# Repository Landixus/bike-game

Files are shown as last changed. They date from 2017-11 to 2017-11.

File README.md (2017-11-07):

# Arduino Bike Game
[Watch the video demo here](https://youtu.be/r04d039daLk)

My 2015 [High School](http://www.scienceandmathacademy.com/) Capstone Project with mentorship from Christopher Rogers.
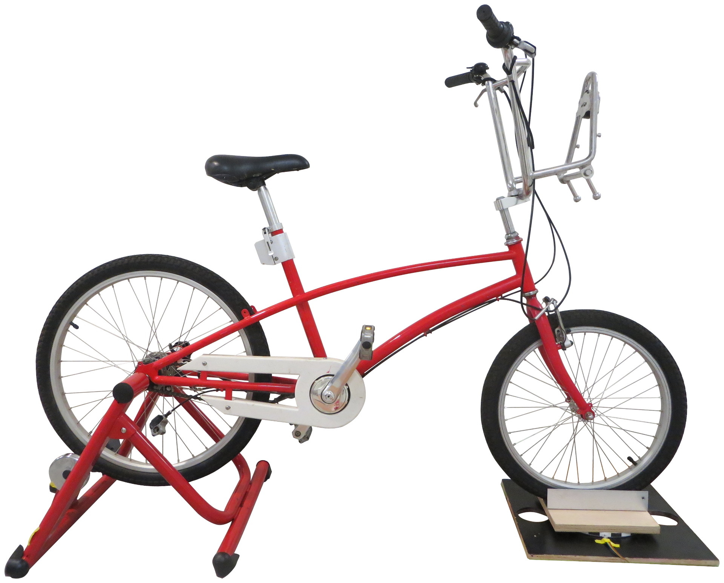
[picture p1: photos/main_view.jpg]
main view
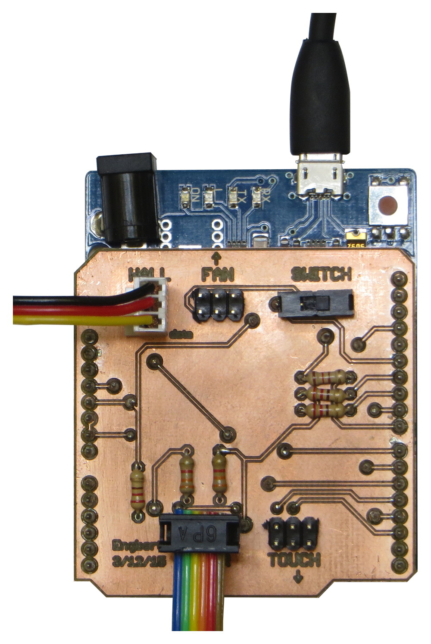
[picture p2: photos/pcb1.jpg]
  

### PURPOSE:
To enable a stationary bike to control computer games so that a biker can race in a game while exercising.

### HOW IT WORKS:
The Arduino Leonardo is plugged into a computer where it emulates a keyboard and constantly measures the bike's speed (RPM) and checks that state of the steering.  In the game, the vehicle’s speed and steering are varied by rapidly modulating the arrow key presses sent to the computer by the Leonardo.
For example: if the bike is above the goal RPM (defined as a constant in the code) then it will effectively press the up arrow continously; and at 50% of the goal speed the up arrow will be pressed 50% of the time on average by the Leonardo.

### RESULTS:
* The system is able to control any racing computer game that can be controlled by arrow keys.
* The faster the biker pedals, the faster the race car will go.
* The sharper the biker turns, the sharper the rac car will turn.
* Read the [project poster](https://github.com/danielengbert/bike-game/blob/master/project_poster.pdf) and watch the [video demo](https://youtu.be/r04d039daLk).

### REQUIREMENTS:
* Arduino Leonardo
* custom printed circuit board (see EAGLE CAD files in the PCB folder)
  * and a few resistors and cables
* hall effect sensor
* neodymium magnet
* 1 IR emmiter and 2 IR receivers (serve as a photointerrupter for the steering)
* lazy susan (for the bike's front tire)
* bike and stationary bike stand

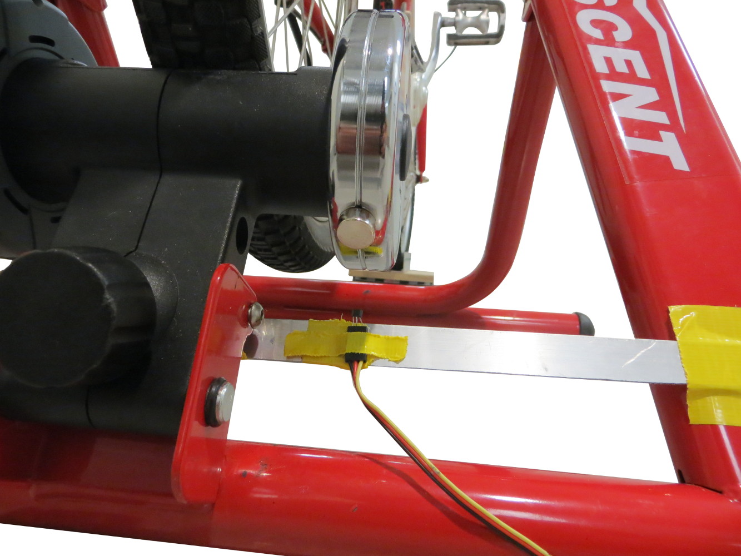
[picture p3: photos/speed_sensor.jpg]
speed sensor
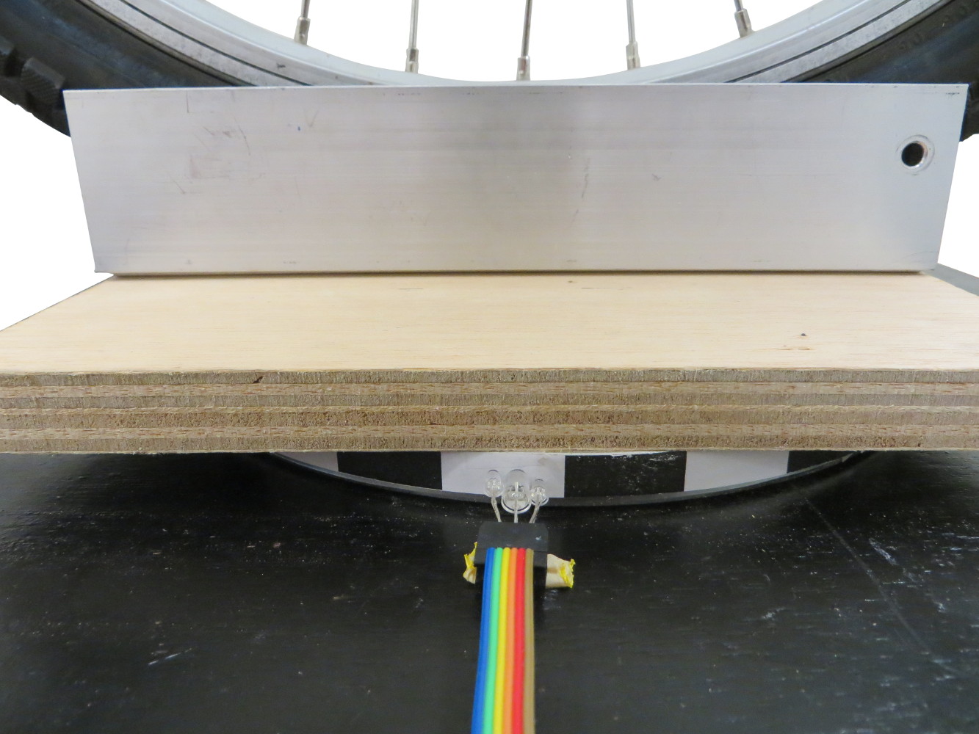
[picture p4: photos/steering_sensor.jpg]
steering sensor
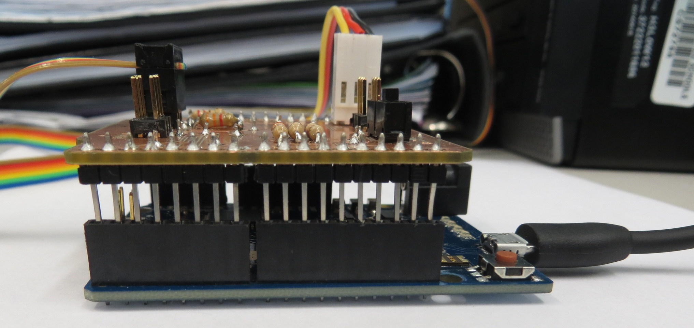
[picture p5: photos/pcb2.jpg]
   

### NOTE:
The next phase of this project would be to add capacitive touch sensor to the bike's handlebar for more game control (like activating turbo) and also to add a fan that blows air on the biker at a strength relative to their bike speed.  Preliminary development of this portion of the project was started and built into the PCB.

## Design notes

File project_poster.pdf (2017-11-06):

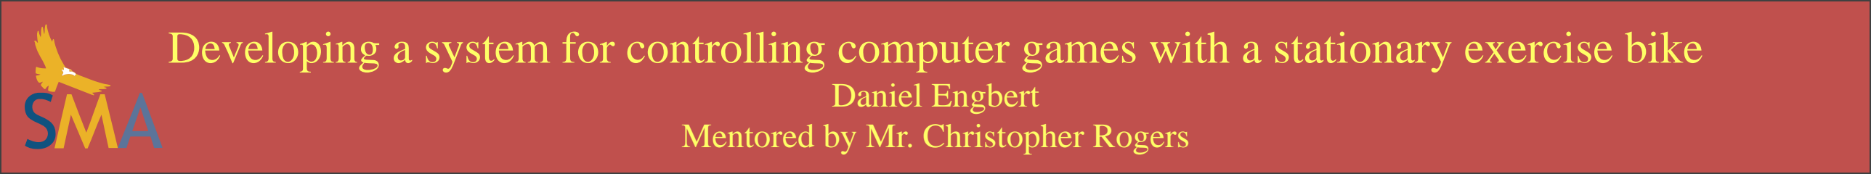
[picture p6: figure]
Daniel Engbert Mentored by Mr. Christopher Rogers

# Developing a system for controlling computer games with a stationary exercise bike

## Introduction

Nearly half the U.S. adult population does not get enough aerobic exercise each week ("Adult Participation," 2013). As a result, many Americans are putting themselves at a greater risk of cardiovascular disease, type 2 diabetes, and even some cancers (“Physical Activity and Health,” 2011).
The idea of exercise is often unappealing to people, and they instead opt for sedentary activities such as video games. This project aimed to combine exercise and video games to create an exciting environment where one can receive the benefits of cardio exercise while playing a computer game. The project focused on creating a system where any computer racing game could be controlled by exercising on a stationary bike.

## Methods and Materials

## Conclusions

## Methods and Materials (cont.)

In order to verify the consistency and accuracy of the system, the calculated rpm values were compared to the actual rpm (as determined by observing the Hall effect sensor with an oscilloscope) for two trials. The distributions of calculated rpm values for the trials are shown in Graph 1 and 2. The low and high rpm trial had standard deviations of 0.593 and 3.16 respectively. The steering was tested for 1000 turn iterations and no issues were present; the program consistently kept track of the position of the front tire.
The variable speed fan was never fully implemented. The Leonardo and Uno were able to successfully communicate the desired fan speed, but the Uno was unable to correctly set the fan speed all of the time. The issues stemmed from the fan failing to consistently receive the IR signal from the Uno.

Centers For Disease Control and Prevention. (2011). Physical activity and health. Retrieved from http://www.cdc.gov/physicalactivity/everyone/health/ Centers For Disease Control and prevention. (2013). Adult participation in aerobic and muscle-strengthening physical activities — United States, 2011. Retrieved from http://www.cdc.gov/mmwr/preview/mmwrhtml/mm6217a2.htm

## References

An Arduino

® Leonardo microcontroller connected to the sensors through a custom PCB and sent keyboard commands to the computer through a USB cable (Figure 2). A computer racing game was then controlled by the keyboard commands sent from the Leonardo. In the computer game, the vehicle’s speed and steering were varied by rapidly modulating the arrow key presses sent to the computer. An Arduino

® Uno was also utilized to receive commands from the Leonardo and to send IR commands to a remote controlled variable speed fan; setting its power level relative to that of the cyclist’s speed.

A bicycle was mounted on a resistance trainer for stationary use (see Figure 1). A magnet was placed on the trainer’s fly wheel so that it would be rotated by the back tire when the user pedaled. A Hall effect sensor was then attached beneath the wheel to allow the cyclist’s speed to be calculated (Figure 3). A bracket was constructed and affixed to a Lazy Susan for the bike’s front tire to rest in. An IR LED and two phototransistors were pointed at a black and white grid bordering the Lazy Susan (Figure 4) allowing the direction and magnitude of the bike’s steering to be measured.

## Results (cont.)

The goal to create a system allowing computer racing games to be controlled by a stationary bike was accomplished. The project’s speed and steering input methods were determined to be sufficient for modulated control of game-play.
The issues with the variable speed fan could be overcome if a sensor was added for the Uno to check the fan’s current speed level. This would enable the Uno to identify when the fan failed to receive a signal, and then resend it as needed.
The project could be further expanded by incorporating a mobile app. The app could allow the user to alter the settings based on the specific computer game, adjust the exercise intensity, and provide feedback on the user’s biking speed. Additionally, a multiplayer setup with two or more bikes could be constructed.

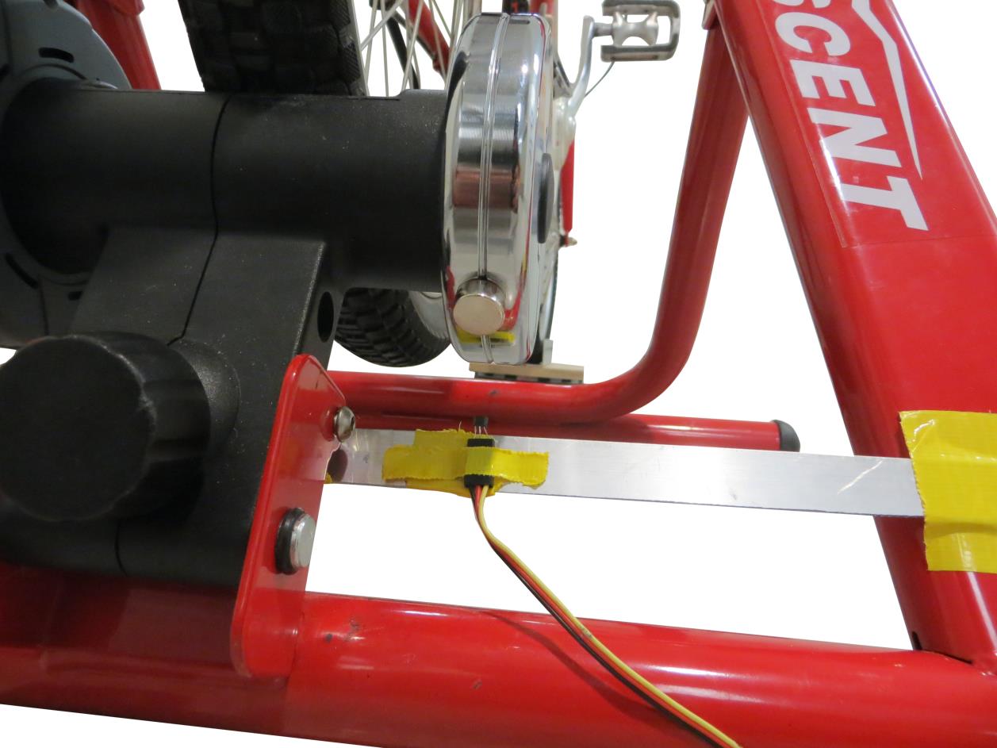
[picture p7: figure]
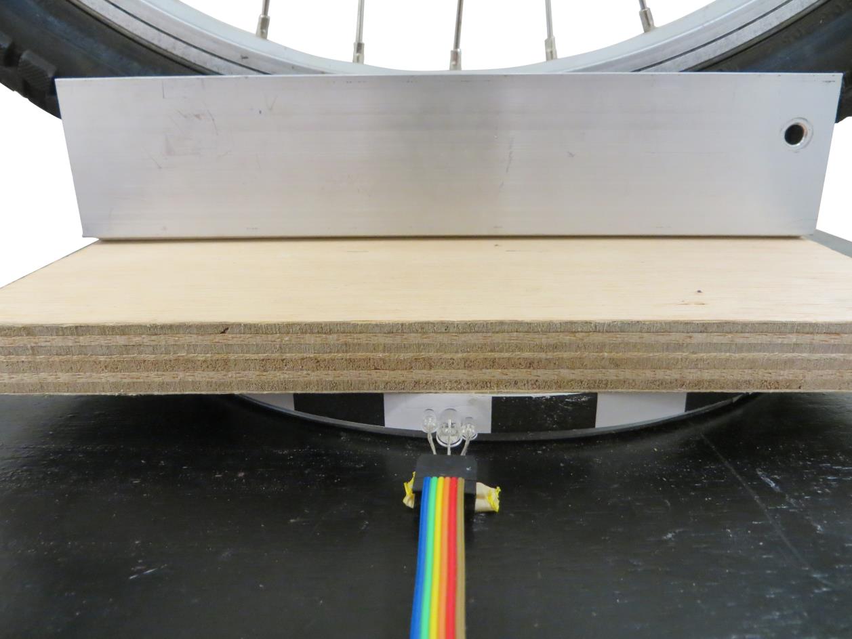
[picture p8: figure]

Figure 3: The Hall effect sensor mounted beneath the fly wheel of the bike stand. A magnet attached to the wheel was detected | Figure 4: The bike’s front tire resting in the Lazy Susan. An IR LED was mounted between two phototransistors pointed at the
by the sensor after each rotation, allowing the user’s speed to be calculated. | black and white grid for measuring the direction and magnitude of the user’s steering.

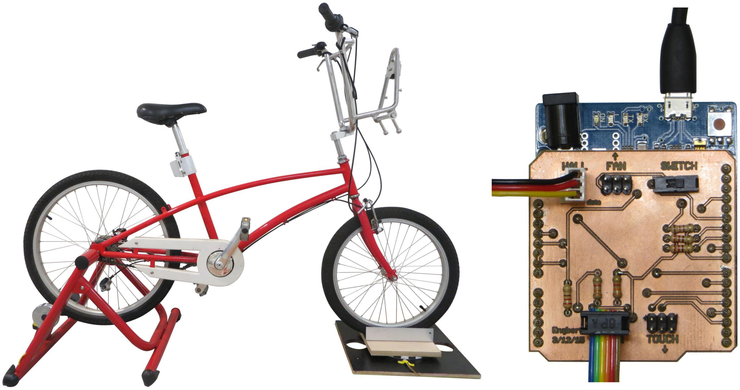
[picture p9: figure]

Figure 1: A bike with its rear wheel mounted on the resistance trainer and the front tire resting in the bracket on the Lazy Susan.

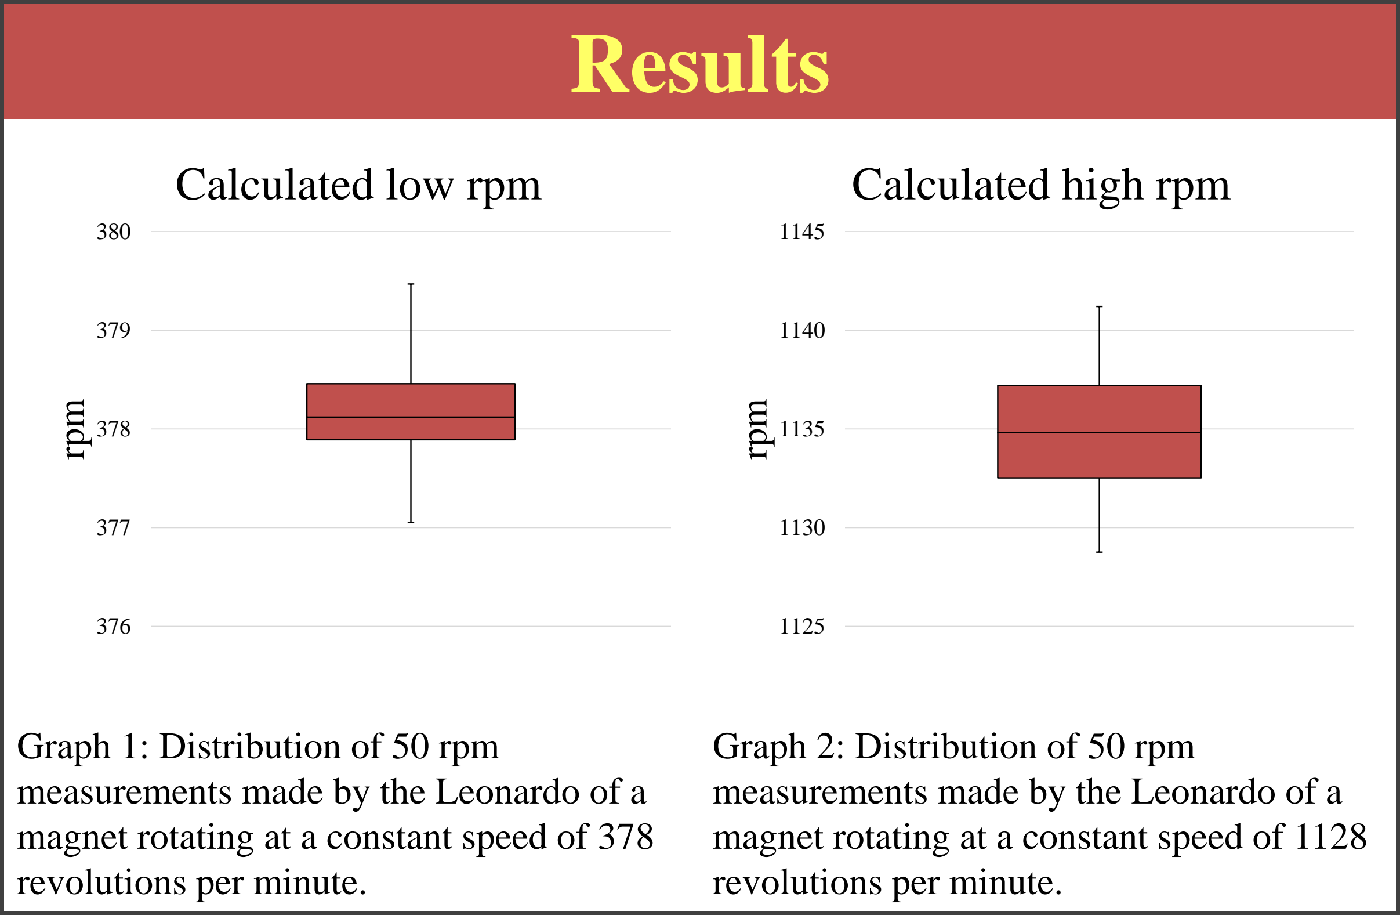
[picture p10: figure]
Results; rpm; Calculated low rpm; Calculated high rpm

Graph 1: Distribution of 50 rpm | Graph 2: Distribution of 50 rpm
measurements made by the Leonardo of a magnet rotating at a constant speed of 378 revolutions per minute. | measurements made by the Leonardo of a magnet rotating at a constant speed of 1128 revolutions per minute.

Figure 2: The custom PCB
plugged into the Arduino®
Leonardo with the connected Hall effect and steering
sensors.

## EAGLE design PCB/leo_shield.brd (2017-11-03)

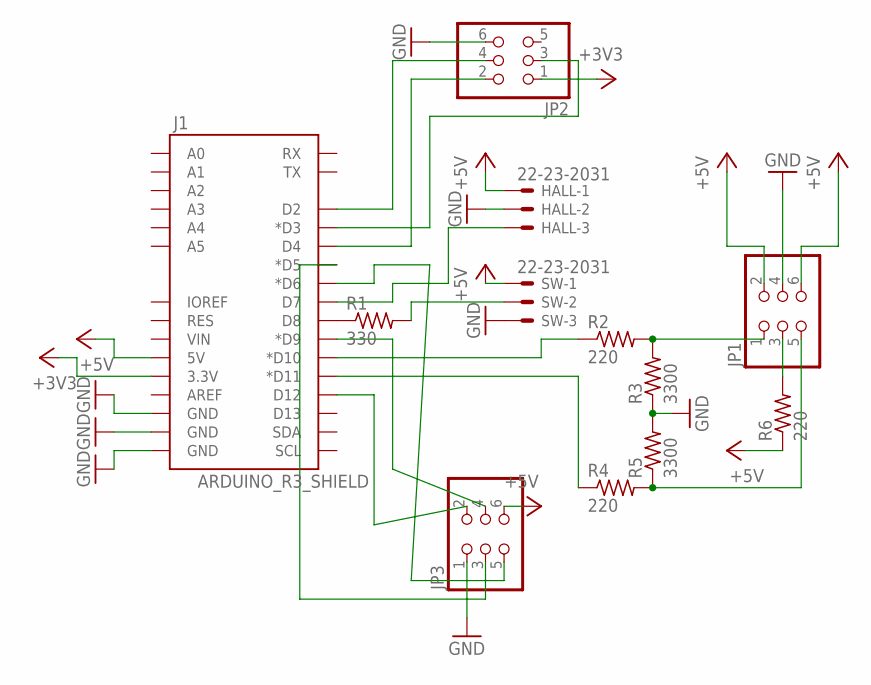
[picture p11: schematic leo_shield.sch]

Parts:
HALL: 22-23-2031
J1: ARDUINO_R3_SHIELD; UNO_R3_SHIELD
JP1, JP2, JP3: PINHD-2X3; 2X03
R1: 330; 0204/7
R2, R4, R6: 220; 0204/7
R3, R5: 3300; 0204/7
SW: 22-23-2031

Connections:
+3V3: J1.3.3V, JP2.1
+5V: HALL.1, J1.5V, JP1.2, JP1.6, JP3.6, R6.1, SW.1
GND: HALL.2, J1.GND@0 (GND), J1.GND@1 (GND), J1.GND@2 (GND), JP1.4, JP2.6, JP3.1, R3.1, R5.2, SW.3
IR: JP1.1, R2.2, R3.2
unnamed: J1.D12, JP3.2
unnamed: JP1.3, R6.2
unnamed: R1.2, SW.2
unnamed: J1.D11 (*D11), R4.1
unnamed: J1.D8, R1.1
unnamed: HALL.3, J1.D7
unnamed: JP1.5, R4.2, R5.1
unnamed: J1.D4, JP2.2
unnamed: J1.D2, JP2.4
unnamed: J1.D3 (*D3), JP2.3
unnamed: J1.D10 (*D10), R2.1
unnamed: J1.D9 (*D9), JP3.4
unnamed: J1.D5 (*D5), JP3.3
unnamed: J1.D6 (*D6), JP3.5

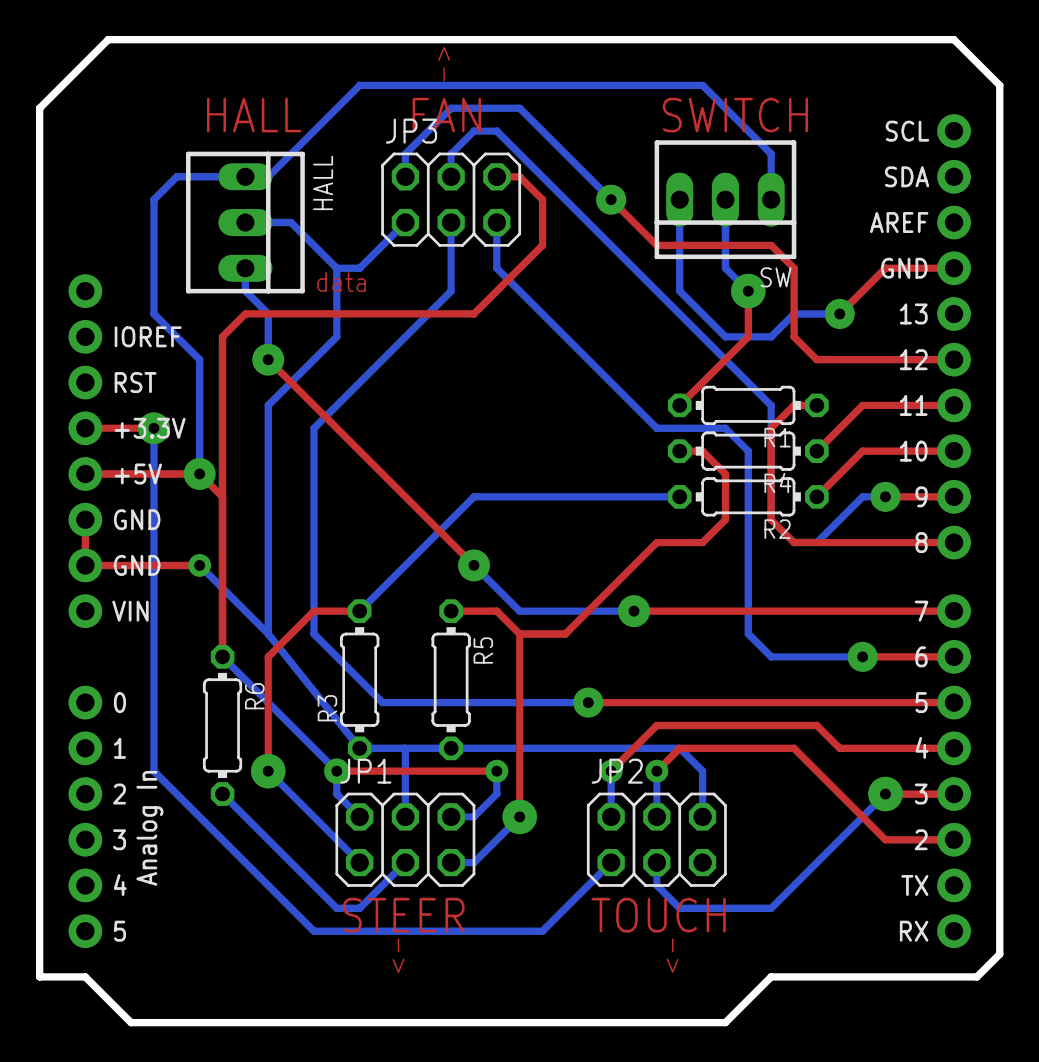
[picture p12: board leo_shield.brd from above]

Board: 2 copper layers, 53.3 x 54.6 mm, 12 parts (0 on the bottom side), 18 nets.

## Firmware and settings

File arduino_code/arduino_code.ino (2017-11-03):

#include "mpr121.h"
#include <Wire.h>
//RPM VARIABLES:
volatile int count = 0; //variable declerations
volatile long cTime = 0; //volatile lets the variable be accessed in all functions
volatile long lastTime = 0;
volatile long period;
volatile double rpm = 0;
//SPEED VARIABLES:
const int goal = 2000;
const int interval = 100;
int speedTime = 0;
double speedStart = 0;
double speedStop; //rename speedspeedStop or speedStop
//STEERING VARIABLES:
double turnStart = 0;
double turnStop;
double factor;
int oldright=0;
int right;
int oldleft=0;
int left;
int same; //value of the last color that both detected
double total = 0;
//TOUCHPAD Variables:
int irqpin = 4;  // Digital 2
boolean touchStates[12]; //array of 12 booleans- keeps track of the previous touch states
boolean state=true;

int sumRPM=0;
int numTurns=0;


//:::SETUP:::
void setup(){
  Serial.begin(9600); //allows the serial monitor to display outputs
  Keyboard.begin();
  Wire.begin();
  attachInterrupt(4, rotationCounter, RISING); //rotationCounter function runs when LEONARDO board pin7 (the interrupt pin 4)
                                               //rises (goes from a low to high)
  pinMode(irqpin, INPUT);
  digitalWrite(irqpin, HIGH); //enable pullup resistor
  mpr121_setup();
  
  pinMode(8, INPUT); //switch pin
  pinMode(10, INPUT); //steering
  pinMode(11, INPUT); //steering

  //Keyboard.press(KEY_UP_ARROW);
}


//:::MAIN:::
void loop()
{

  while (digitalRead(8) == LOW) //stops the void loop here while the switch is making pin 8 high
    {
     Keyboard.releaseAll();
     if(state)
       {
       Serial.println("____PAUSED____");
       total=0; //steering must be centered at end of pause
       state=false;
       }
     }
      
 if(!state)
   {
   Serial.println("____GO____");
   state=true;
   //Keyboard.press(KEY_UP_ARROW);
   }
  

  //readTouchInputs();
  //controlSpeed();
  //controlSteering();
}


void controlSpeed()
{
  if( millis() >= speedStart && (millis() - lastTime) < 100 )  //presses up arrow for 500* rpm/goal (during which time this if shouldn't run again) 
    {
    //Serial.println("forward"); 
    Keyboard.press(KEY_UP_ARROW);
    speedStart = millis() + interval; //time for the NEXT speed cycle to begin at
    speedStop = millis() + interval * rpm/goal;
    
    if(rpm/goal > 1.0)
      speedStop = speedStart;
    }
    
  if(millis() >= speedStop) //release up arrow for rest time 
    Keyboard.release(KEY_UP_ARROW);
}


void controlSteering()
{
 left = digitalRead(10); //switched these two after printing the PCB
 right = digitalRead(11);  
 
 if((right != oldright) || (left != oldleft)) //a 1" turn occured
   {//Serial.print(left); Serial.print(", "); Serial.println(right);
   numTurns++;
   if(right == left)
     same = right; //save the value both sensors are on
   else
     same = -1;   
   
  if(right == oldleft)
    {total--; Serial.print("LEFT");}
  if(left == oldright)
    {total++; Serial.print("RIGHT");}
  Serial.print(" Total = "); Serial.print(total); Serial.print("  "); Serial.print(total/5 * 100); Serial.print("%"); Serial.print("   turned "); Serial.print(numTurns); Serial.println(" times");
   }
   
 oldright = right;
 oldleft = left;

 if(millis() >= turnStart)        //press up arrow for 500* rpm/goal (during which time this if shouldn't run again) 
  {
  if(total < -1)
    Keyboard.press(KEY_LEFT_ARROW);
  if(total > 1)
    Keyboard.press(KEY_RIGHT_ARROW);
         
  turnStop = millis() + interval * abs(total)/10; //max rotation when total=5
  turnStart = millis() + interval; //time for the NEXT speed cycle to begin at
  if(abs(total)/10 > 1)
    turnStop = turnStart;
  
   }
 
 if(millis() >= turnStop) //release arrow for rest time (remainder of interval)
   {
   Keyboard.release(KEY_LEFT_ARROW);
   Keyboard.release(KEY_RIGHT_ARROW);
   }
}


void rotationCounter() //variables modified within the attached function should be volatile
{
  lastTime = cTime;  //lastTime = time that the previous rotation occured at
  cTime = millis();   //time (in msec) since the arduino started
  count++;          //adds one to the number of revolutions that have occured
  period = cTime - lastTime; //time for the last rotation to occur
  rpm = 1.0 / (period / 1000.0 / 60.0);
  if(count%25==0)
    {Serial.print("***"); Serial.print(count); Serial.println("***");}
  Serial.print("rpm: "); Serial.println(rpm);
}

void sendFan(String cmd, int val)
{
  if(cmd == "power")
    digitalWrite(5, HIGH);
  else
    digitalWrite(5, LOW);
  
  if(cmd == "speed")
  {
    if(val==1)
    {
      digitalWrite(6, LOW);
      digitalWrite(9, HIGH);
    }
    if(val==2)
    {
     digitalWrite(6, HIGH);
     digitalWrite(9, LOW); 
    }
    
    if(val == 3)
    {
     digitalWrite(6, HIGH);
     digitalWrite(9, HIGH); 
    }
  }
  
  digitalWrite(12, HIGH);
  delay(10);
  digitalWrite(12, LOW);  
}


void readTouchInputs(){
  if(!checkInterrupt()){
    //read the touch state from the MPR121
    Wire.requestFrom(0x5A,2); 
    
    byte LSB = Wire.read();
    byte MSB = Wire.read();
    
    uint16_t touched = ((MSB << 8) | LSB); //16bits that make up the touch states

    
    for (int i=0; i < 12; i++){  // Check what electrodes were pressed
      if(touched & (1<<i))
      {
        if(touchStates[i] == 0){
          //pin i was just touched
          Serial.print("pin ");
          Serial.print(i);
          Serial.println(" touched");
        
        }else if(touchStates[i] == 1){
          //pin i is still being touched
        }  
      
        touchStates[i] = 1;      
      }else{
        if(touchStates[i] == 1){
          Serial.print("pin ");
          Serial.print(i);
          Serial.println(" released");
          
          //pin i is no longer being touched
       }
        //if(touchStates[0] == 1) //activate nitro
          //Keyboard.write('n');
        //touchStates[i] = 0;
      }
    
    }
    
  }
}


void mpr121_setup(void){

  set_register(0x5A, ELE_CFG, 0x00); 
  
  // Section A - Controls filtering when data is > baseline.
  set_register(0x5A, MHD_R, 0x01);
  set_register(0x5A, NHD_R, 0x01);
  set_register(0x5A, NCL_R, 0x00);
  set_register(0x5A, FDL_R, 0x00);

  // Section B - Controls filtering when data is < baseline.
  set_register(0x5A, MHD_F, 0x01);
  set_register(0x5A, NHD_F, 0x01);
  set_register(0x5A, NCL_F, 0xFF);
  set_register(0x5A, FDL_F, 0x02);
  
  // Section C - Sets touch and release thresholds for each electrode
  set_register(0x5A, ELE0_T, TOU_THRESH);
  set_register(0x5A, ELE0_R, REL_THRESH);
 
  set_register(0x5A, ELE1_T, TOU_THRESH);
  set_register(0x5A, ELE1_R, REL_THRESH);
  
  set_register(0x5A, ELE2_T, TOU_THRESH);
  set_register(0x5A, ELE2_R, REL_THRESH);
  
  set_register(0x5A, ELE3_T, TOU_THRESH);
  set_register(0x5A, ELE3_R, REL_THRESH);
  
  set_register(0x5A, ELE4_T, TOU_THRESH);
  set_register(0x5A, ELE4_R, REL_THRESH);
  
  set_register(0x5A, ELE5_T, TOU_THRESH);
  set_register(0x5A, ELE5_R, REL_THRESH);
  
  set_register(0x5A, ELE6_T, TOU_THRESH);
  set_register(0x5A, ELE6_R, REL_THRESH);
  
  set_register(0x5A, ELE7_T, TOU_THRESH);
  set_register(0x5A, ELE7_R, REL_THRESH);
  
  set_register(0x5A, ELE8_T, TOU_THRESH);
  set_register(0x5A, ELE8_R, REL_THRESH);
  
  set_register(0x5A, ELE9_T, TOU_THRESH);
  set_register(0x5A, ELE9_R, REL_THRESH);
  
  set_register(0x5A, ELE10_T, TOU_THRESH);
  set_register(0x5A, ELE10_R, REL_THRESH);
  
  set_register(0x5A, ELE11_T, TOU_THRESH);
  set_register(0x5A, ELE11_R, REL_THRESH);
  
  // Section D
  // Set the Filter Configuration
  // Set ESI2
  set_register(0x5A, FIL_CFG, 0x04);
  
  // Section E
  // Electrode Configuration
  // Set ELE_CFG to 0x00 to return to standby mode
  set_register(0x5A, ELE_CFG, 0x0C);  // Enables all 12 Electrodes
  
  
  // Section F
  // Enable Auto Config and auto Reconfig
  /*set_register(0x5A, ATO_CFG0, 0x0B);
  set_register(0x5A, ATO_CFGU, 0xC9);  // USL = (Vdd-0.7)/vdd*256 = 0xC9 @3.3V   set_register(0x5A, ATO_CFGL, 0x82);  // LSL = 0.65*USL = 0x82 @3.3V
  set_register(0x5A, ATO_CFGT, 0xB5);*/  // Target = 0.9*USL = 0xB5 @3.3V
  
  set_register(0x5A, ELE_CFG, 0x0C);
  
}


boolean checkInterrupt(void){
  return digitalRead(irqpin);
}


void set_register(int address, unsigned char r, unsigned char v){
    Wire.beginTransmission(address);
    Wire.write(r);
    Wire.write(v);
    Wire.endTransmission();
}

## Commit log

2017-11-03 Initialized repository with code and PCB files from my 2015 high school project.
    [leo_shield.brd, leo_shield.sch]
2017-11-06 Added steering pattern

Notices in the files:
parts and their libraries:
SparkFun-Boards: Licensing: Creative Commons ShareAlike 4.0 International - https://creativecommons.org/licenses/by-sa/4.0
